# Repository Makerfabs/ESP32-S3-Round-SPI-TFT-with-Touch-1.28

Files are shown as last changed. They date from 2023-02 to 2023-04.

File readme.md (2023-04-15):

# ESP32-S3 Round SPI TFT with Touch 1.28"

```c++
/*
Version:        V1.1
Author:            Vincent
Create Date:    2023/2/18
Note:
        2023/4/15 V1.1:Add TFT_eSPI support.
*/
```

[TOC]

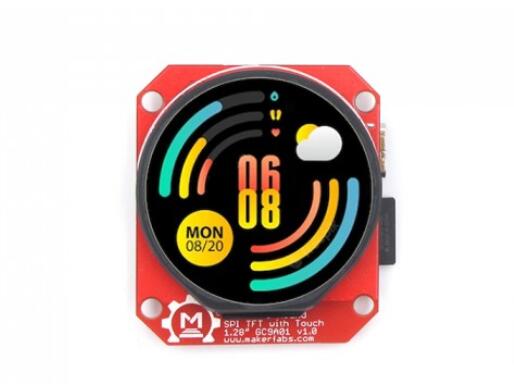
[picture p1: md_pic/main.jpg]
main


# Makerfabs

[Makerfabs home page](https://www.makerfabs.com/)

[Makerfabs Wiki](https://wiki.makerfabs.com/)

# ESP32-S3 Round SPI TFT with Touch 1.28"

## Intruduce

Product Link ：[ESP32-S3 Round SPI TFT with Touch 1.28"](https://www.makerfabs.com/esp32-s3-round-spi-tft-with-touch-1-28-inch.html)

Wiki Link : []()

The ESP32-S3 round display with touch can be a great tool for your applications such as smartwatch.

We selected the ESP32-S3 generation as the controller, with 16MB Flash and 8MB PSRAM, enough for most IOT applications; The round display is 240x240 resolution 1.28", colorful RGB, with capacitive touch, it communicates with ESP32 with SPI interface, so there enough GPIO left for expansion applications.

## Feature

- Controller: ESP32-S3
- Wireless: WiFi& Bluetooth 5.0
- LCD: 1.28", 240*240 resolution, driver GC9A01
- LCD interface: SPI
- Touch Panel Driver: CST816S
- USB: USB Native
- Power Supply: USB Type-C 5.0V(4.0V~5.25V); 3.7V Lipo battery
- Button: Flash button and reset button
- Mabee interface: 1*I2C; 1*GPIO
- MicroSD: Yes
- Arduino support: Yes
- Operation temperature: -40℃ to +85℃

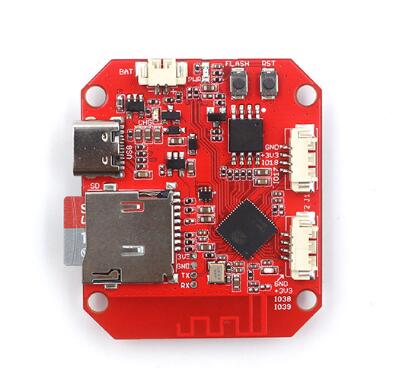
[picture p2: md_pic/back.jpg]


# Code

## Complier Option

- Install board : ESP32 .
- Install libraries：

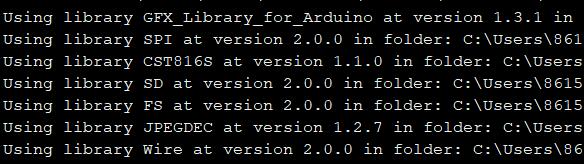
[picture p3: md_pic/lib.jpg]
library


- Use type-c use cable connect USB to PC.
- Select "ESP32-S3 DEV Module"

"mf_Lvgl" library is modified from Lvgl library (version 8.3.2). 

If you want use lvgl, please unzip "lib/mf_Lvgl.zip" and copy to arduino library directory.

## Factory test program

\example\esp32s3_round_test

You can run this file test if you feel that your hardware is not working properly. 

Need copy logo_240240.jpg to sd card.

## Example

### TFT_eSPI demo

Add TFT_eSPI support.

Library version is 2.5.0

And cover "User_Setuo.h" to library directry.

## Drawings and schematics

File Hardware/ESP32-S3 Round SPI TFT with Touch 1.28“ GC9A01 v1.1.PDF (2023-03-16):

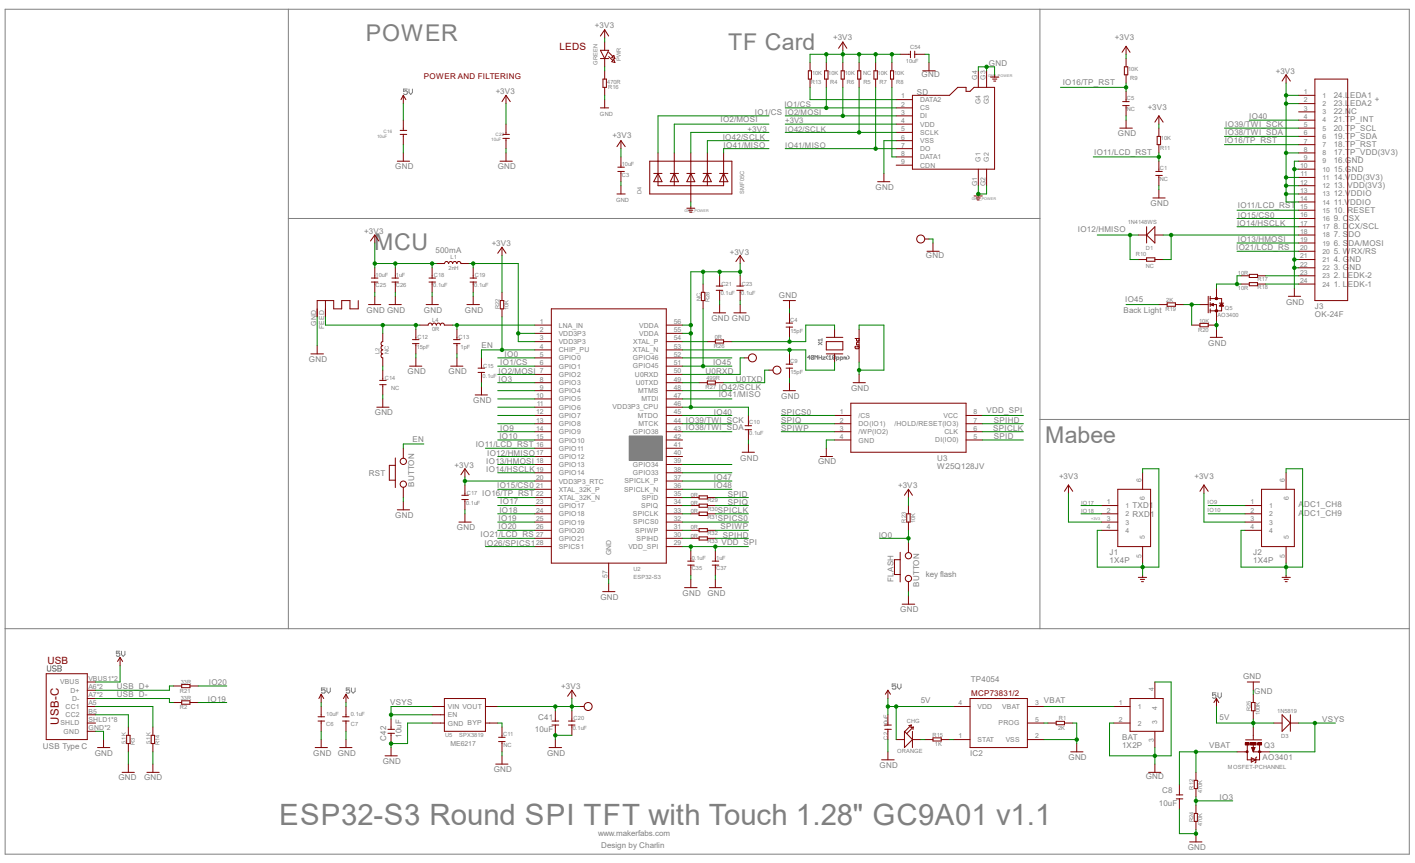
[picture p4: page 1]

IO13/HMOSI R20 | 19 19

key flash ESP32-S3 Round SPI TFT with Touch 1.28" GC9A01 v1.1

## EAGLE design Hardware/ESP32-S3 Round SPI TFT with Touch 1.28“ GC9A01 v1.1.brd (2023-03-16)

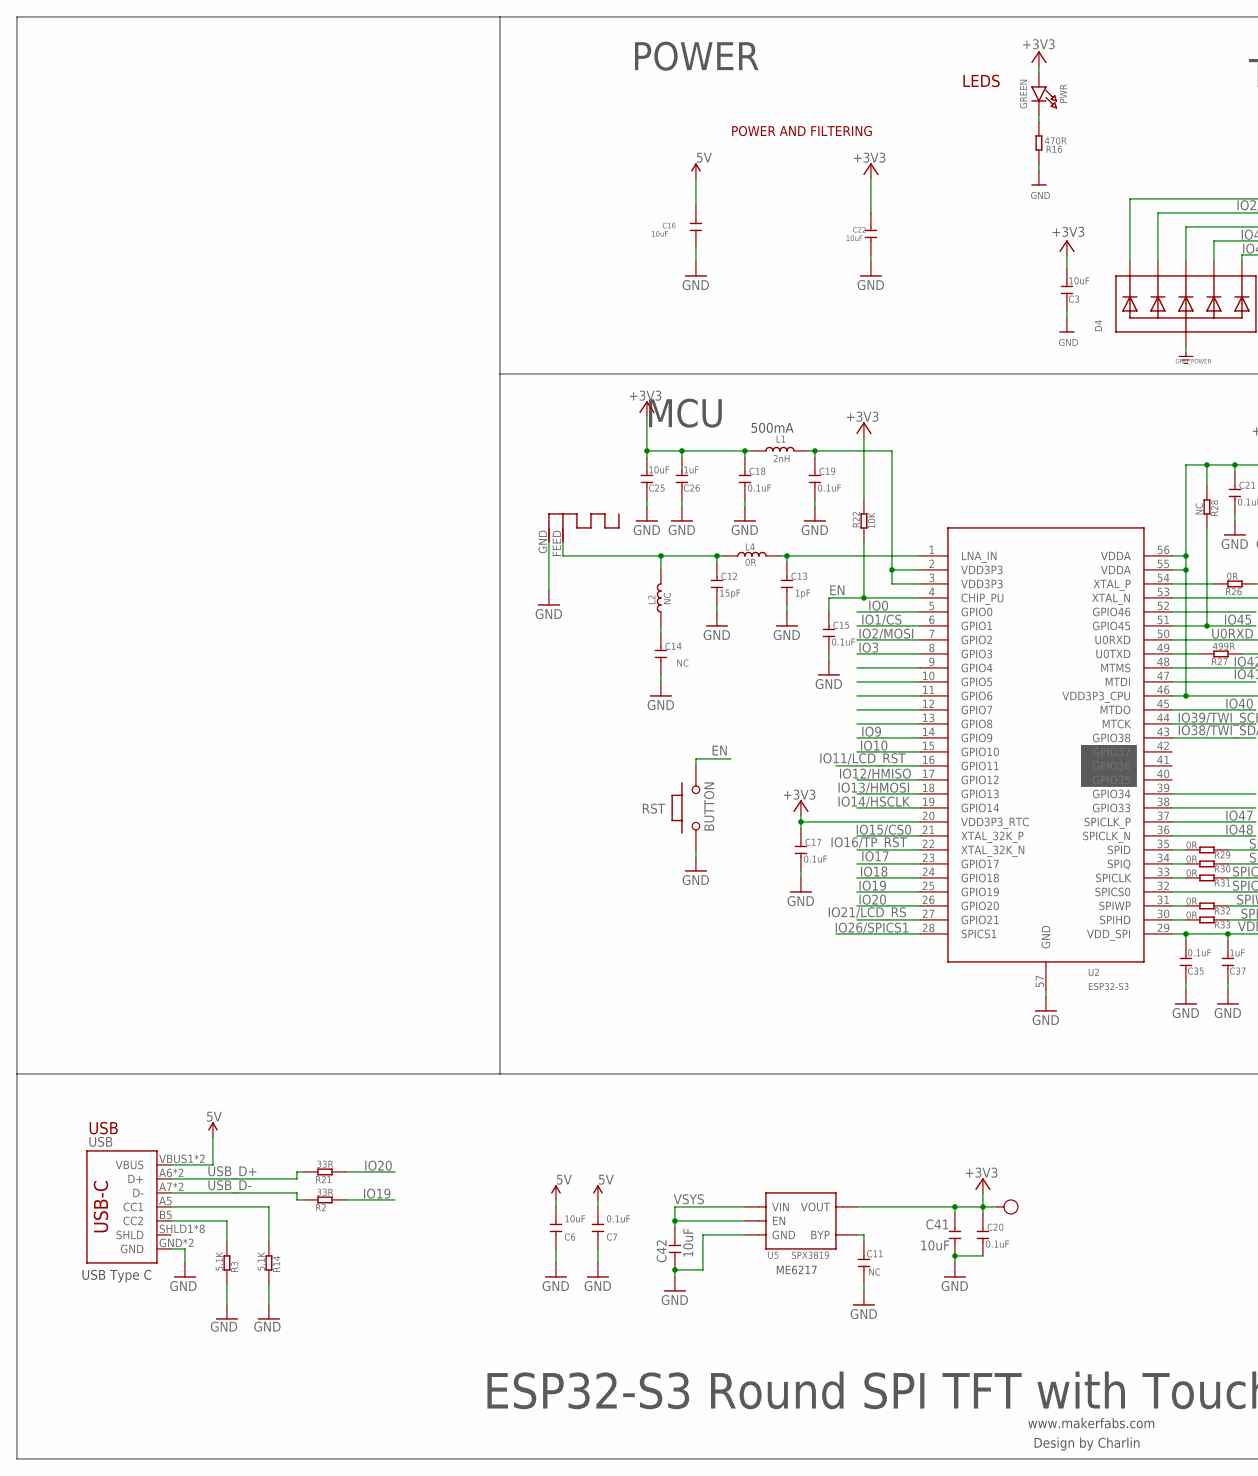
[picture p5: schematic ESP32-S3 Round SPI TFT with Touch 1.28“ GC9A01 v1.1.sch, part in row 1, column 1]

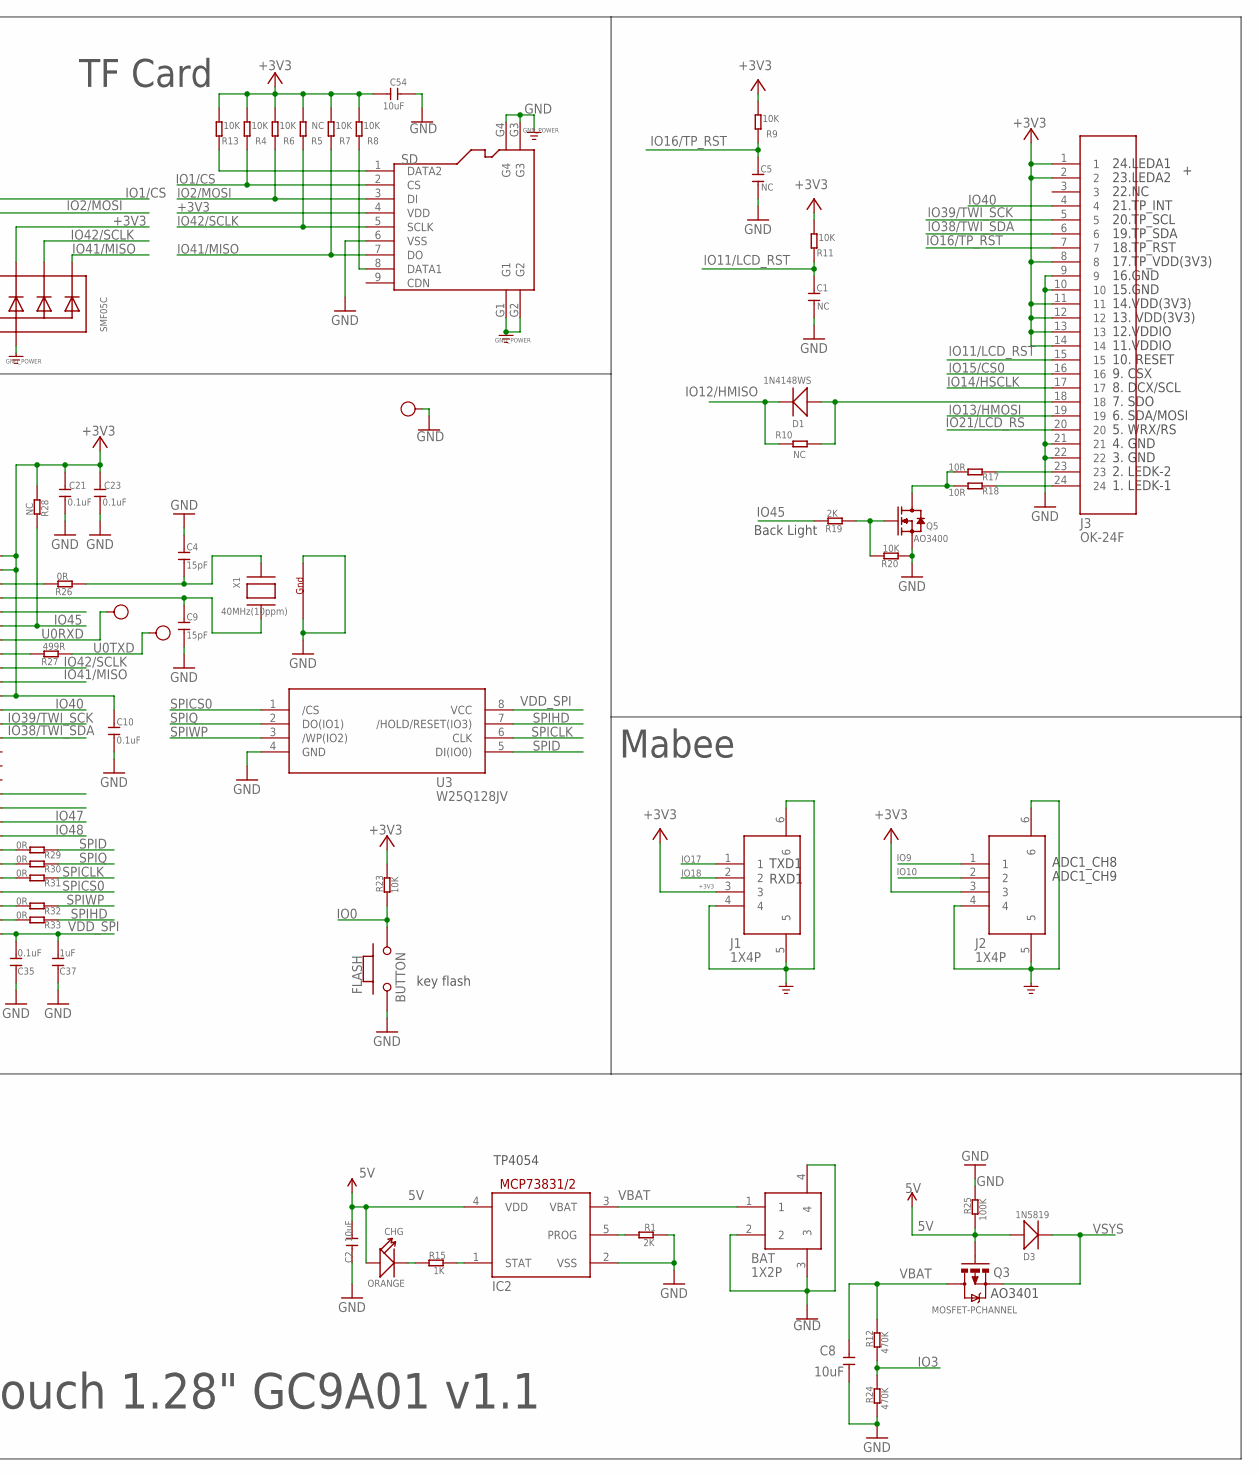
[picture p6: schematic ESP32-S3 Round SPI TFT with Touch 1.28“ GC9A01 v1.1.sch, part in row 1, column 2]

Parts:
3V3: TEST-POINT'4545'; TP-D45MIL; PARTNO DNP
ANT1: ANTENNA; RN-ANT
BAT: 1X2P; 1X2P-SMT1.25MM
C1, C5, C11, C14: NC; DISCRETE_C0402
C2, C8, C16, C22, C41, C42: 10uF; C0603
C3, C6, C25, C54: 10uF; DISCRETE_C0603
C4, C9, C12: 15pF; DISCRETE_C0402
C7, C35: 0.1uF; DISCRETE_C0603
C10, C15, C17, C18, C19, C20, C21, C23: 0.1uF; DISCRETE_C0402
C13: 1pF; DISCRETE_C0402
C26, C37: 1uF; DISCRETE_C0603
CHG: ORANGE; D0603
D1: 1N4148WS; SOD323
D3: 1N5819; SOD323
D4: SMF05C; SOT363
FLASH: BUTTON; 157SW
GND: TEST-POINT'4545'; TP-D45MIL
IC2: MCP73831/OT; SOT23-5L
J1, J2: 1X4P; 1X4P-SMT1.25MM
J3: OK-24F; OK-24F-0.4
L1: 2nH; DISCRETE_L0603
L2: NC; DISCRETE_L0402
L4: 0R; DISCRETE_L0402
PWR: GREEN; CHIPLED_0805_NOOUTLINE
Q3: MOSFET-PCHANNEL; SOT23-3
Q5: AO3400; SOT23@1
R1, R19: 2K; DISCRETE_R0402
R2, R21: 33R; DISCRETE_R0402
R3, R14: 5.1K; DISCRETE_R0402
R4, R6, R7, R8, R9, R11, R13, R20, R22, R23: 10K; DISCRETE_R0402
R5, R28: NC; DISCRETE_R0402
R10: NC; R0603
R12, R24: 470K; DISCRETE_R0402
R15: 1K; DISCRETE_R0402
R16: 470R; DISCRETE_R0402
R17, R18: 10R; DISCRETE_R0402
R25: 100K; DISCRETE_R0402
R26, R29, R30, R31, R32, R33: 0R; DISCRETE_R0402
R27: 499R; DISCRETE_R0402
RST: BUTTON; 157SW
RX: TEST-POINT'4545'; TP-D45MIL; PARTNO DNP
SD: HOLDER-MICROSD-9P; 9P-SMD-W/-RING
TX: TEST-POINT'4545'; TP-D45MIL; PARTNO DNP
U2: ESP32-S3; QFN56-7*7MM
U3: W25Q128JV; SOIC-8-208MIL
U5: SPX3819; SOT23-5
USB: USB_C5; USB-C-16P-5
X1: 40MHz(10ppm); NX3225

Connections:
5V: C2.2, C6.2, C7.2, C16.1, CHG.+, D3.+, IC2.4 (VDD), Q3.1 (G), R25.1, USB.VBUS1 (VBUS), USB.VBUS2 (VBUS)
+3V3: 3V3.T, C3.2, C10.2, C17.2, C18.2, C20.2, C21.2, C22.1, C23.2, C25.2, C26.2, C41.2, C54.2, D4.4 (C3), J1.3, J2.3, J3.1, J3.2, J3.8, J3.11, J3.12, J3.13, J3.14, L1.1, PWR.A, R4.2, R5.2, R6.2, R7.2, R8.2, R9.2, R11.2, R13.2, R22.2, R23.2, R28.1, SD.4 (VDD), U2.20 (VDD3P3_RTC), U2.46 (VDD3P3_CPU), U2.55 (VDDA), U2.56 (VDDA), U5.5 (VOUT)
EN: C15.2, R22.1, RST.2, U2.4 (CHIP_PU)
GND: ANT1.GND, BAT.2, BAT.3, BAT.4, C1.1, C2.1, C3.1, C4.2, C5.1, C6.1, C7.1, C8.1, C9.1, C10.1, C11.1, C12.1, C13.1, C14.1, C15.1, C16.2, C17.1, C18.1, C19.1, C20.1, C21.1, C22.2, C23.1, C25.1, C26.1, C35.1, C37.1, C41.1, C42.1, C54.1, D4.2 (A), FLASH.1, GND.T, IC2.2 (VSS), J1.4, J1.5, J1.6, J2.4, J2.5, J2.6, J3.9, J3.10, J3.21, J3.22, Q5.2 (S), R1.2, R3.2, R14.2, R16.1, R20.1, R24.1, R25.2, RST.1, SD.6 (VSS), SD.G1, SD.G2, SD.G3, SD.G4, U2.57 (GND), U3.4 (GND), U5.2 (GND), USB.GND, USB.GND2 (GND), X1.2 (G2), X1.4 (G1)
IO0: FLASH.2, R23.1, U2.5 (GPIO0)
IO1/CS: D4.1 (C1), R4.1, SD.2 (CS), U2.6 (GPIO1)
IO2/MOSI: D4.3 (C2), R6.1, SD.3 (DI), U2.7 (GPIO2)
IO3: R12.1, R24.2, U2.8 (GPIO3)
IO9: J2.1, U2.14 (GPIO9)
IO10: J2.2, U2.15 (GPIO10)
IO11/LCD_RST: C1.2, J3.15, R11.1, U2.16 (GPIO11)
IO12/HMISO: D1.-, R10.1, U2.17 (GPIO12)
IO13/HMOSI: J3.19, U2.18 (GPIO13)
IO14/HSCLK: J3.17, U2.19 (GPIO14)
IO15/CS0: J3.16, U2.21 (XTAL_32K_P)
IO16/TP_RST: C5.2, J3.7, R9.1, U2.22 (XTAL_32K_N)
IO17: J1.1, U2.23 (GPIO17)
IO18: J1.2, U2.24 (GPIO18)
IO19: R2.1, U2.25 (GPIO19)
IO20: R21.1, U2.26 (GPIO20)
IO21/LCD_RS: J3.20, U2.27 (GPIO21)
IO26/SPICS1: U2.28 (SPICS1)
IO38/TWI_SDA: J3.6, U2.43 (GPIO38)
IO39/TWI_SCK: J3.5, U2.44 (MTCK)
IO40: J3.4, U2.45 (MTDO)
IO41/MISO: D4.6 (C5), R7.1, SD.7 (DO), U2.47 (MTDI)
IO42/SCLK: D4.5 (C4), R5.1, SD.5 (SCLK), U2.48 (MTMS)
IO45: R19.2, R28.2, U2.51 (GPIO45)
IO47: U2.37 (SPICLK_P)
IO48: U2.36 (SPICLK_N)
unnamed: D1.+, J3.18, R10.2
unnamed: IC2.5 (PROG), R1.1
unnamed: R14.1, USB.A5 (CC1)
unnamed: PWR.C, R16.2
unnamed: R3.1, USB.B5 (CC2)
unnamed: Q5.1 (G), R19.1, R20.2
unnamed: J3.23, R17.1
unnamed: Q5.3 (D), R17.2, R18.2
unnamed: CHG.-, R15.1
unnamed: IC2.1 (STAT), R15.2
unnamed: ANT1.FEED, C12.2, L2.2, L4.1
unnamed: C13.2, L4.2, U2.1 (LNA_IN)
unnamed: R29.2, U2.35 (SPID)
unnamed: C19.2, L1.2, U2.2 (VDD3P3), U2.3 (VDD3P3)
unnamed: C14.2, L2.1
unnamed: R30.2, U2.34 (SPIQ)
unnamed: R26.2, U2.54 (XTAL_P)
unnamed: R31.2, U2.33 (SPICLK)
unnamed: R32.2, U2.31 (SPIWP)
unnamed: R33.2, U2.30 (SPIHD)
unnamed: R13.1, SD.1 (DATA2)
unnamed: R8.1, SD.8 (DATA1)
unnamed: R27.2, U2.49 (U0TXD)
unnamed: C9.2, U2.53 (XTAL_N), X1.3 (X2)
unnamed: C4.1, R26.1, X1.1 (X1)
unnamed: J3.24, R18.1
unnamed: C11.2, U5.4 (BYP)
SPICLK: R31.1, U3.6 (CLK)
SPICS0: U2.32 (SPICS0), U3.1 (/CS)
SPID: R29.1, U3.5 (DI(IO0))
SPIHD: R33.1, U3.7 (/HOLD/RESET(IO3))
SPIQ: R30.1, U3.2 (DO(IO1))
SPIWP: R32.1, U3.3 (/WP(IO2))
U0RXD: RX.T, U2.50 (U0RXD)
U0TXD: R27.1, TX.T
USB_D+: R21.2, USB.A6 (D+), USB.B6 (D+)
USB_D-: R2.2, USB.A7 (D-), USB.B7 (D-)
VBAT: BAT.1, C8.2, IC2.3 (VBAT), Q3.3 (D), R12.2
VDD_SPI: C35.2, C37.2, U2.29 (VDD_SPI), U3.8 (VCC)
VSYS: C42.2, D3.-, Q3.2 (S), U5.1 (VIN), U5.3 (EN)

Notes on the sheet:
www.makerfabs.com
Design by Charlin
LEDS
POWER AND FILTERING
key flash
ESP32-S3 Round SPI TFT with Touch 1.28" GC9A01 v1.1
POWER
TF Card
USB
USB Type C
Mabee
MCU
500mA
ME6217
1. LEDK-1
2. LEDK-2
3. GND
4. GND
5. WRX/RS
6. SDA/MOSI
7. SDO
8. DCX/SCL
9. CSX
10. RESET
11.VDDIO
12.VDDIO
13. VDD(3V3)
14.VDD(3V3)
15.GND
16.GND
17.TP_VDD(3V3)
18.TP_RST
19.TP_SDA
20.TP_SCL
21.TP_INT
22.NC
23.LEDA2
24.LEDA1
Back Light
ADC1_CH8

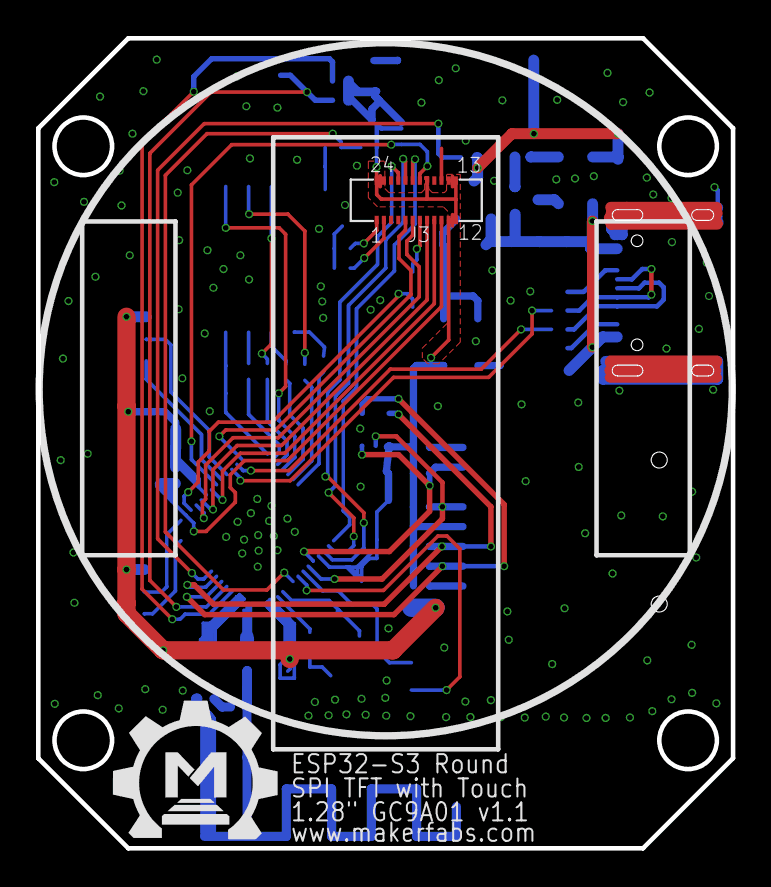
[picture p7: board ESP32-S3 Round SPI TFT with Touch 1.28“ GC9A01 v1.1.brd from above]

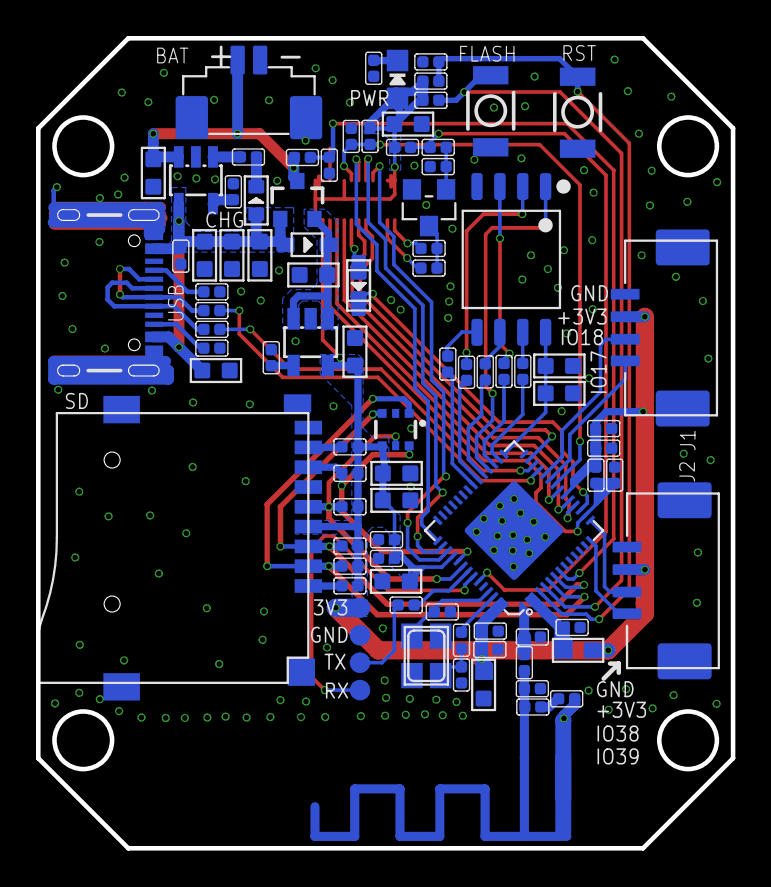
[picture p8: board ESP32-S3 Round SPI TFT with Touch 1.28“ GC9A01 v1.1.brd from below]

Board: 2 copper layers, 38.6 x 45.0 mm, 92 parts (90 on the bottom side), 67 nets.

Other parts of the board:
U$1: MAKERFABS_0.3

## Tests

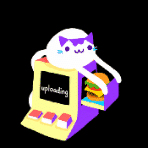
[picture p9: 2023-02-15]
example/s3_round_gif/gif/test3.gif

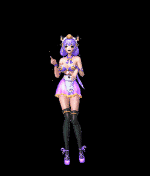
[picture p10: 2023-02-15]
example/s3_round_gif/gif/test4.gif

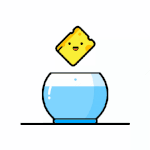
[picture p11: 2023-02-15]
example/s3_round_gif/gif/test1.gif

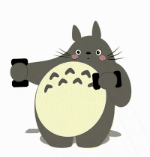
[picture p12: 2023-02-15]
example/s3_round_gif/gif/test2.gif

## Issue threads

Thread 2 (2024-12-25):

error: 'USBSerial' was not declared in this scope; did you mean 'Serial'?

r03ert0, 2024-12-25:
Hello,

When I try to upload esp32s3_round_test.ino to a matouch 1.28, I get the following error:

```
ESP32-S3-Round-SPI-TFT-with-Touch-1.28-main/example/esp32s3_round_test/esp32s3_round_test.ino: In function 'void setup()':
esp32s3_round_test:34:5: error: 'USBSerial' was not declared in this scope; did you mean 'Serial'?
   34 |     USBSerial.begin(115200);
      |     ^~~~~~~~~
      |     Serial
Multiple libraries were found for "SD.h"
 Used: /Users/roberto/Library/Arduino15/packages/esp32/hardware/esp32/3.1.0/libraries/SD
 Not used: /Users/roberto/Documents/Arduino/libraries/SD
exit status 1
'USBSerial' was not declared in this scope; did you mean 'Serial'?
```

what can be wrong?

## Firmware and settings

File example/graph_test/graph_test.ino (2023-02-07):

#include <Arduino_GFX_Library.h>

#define TFT_BLK 45
#define TFT_RES 11

#define TFT_CS 15
#define TFT_MOSI 13
#define TFT_MISO 12
#define TFT_SCLK 14
#define TFT_DC 21

Arduino_ESP32SPI *bus = new Arduino_ESP32SPI(TFT_DC, TFT_CS, TFT_SCLK, TFT_MOSI, TFT_MISO, HSPI, true); // Constructor

Arduino_GFX *gfx = new Arduino_GC9A01(bus, TFT_RES, 0 /* rotation */, true /* IPS */);

int32_t w, h, n, n1, cx, cy, cx1, cy1, cn, cn1;
uint8_t tsa, tsb, tsc, ds;

void setup()
{
    USBSerial.begin(115200);

    pinMode(TFT_BLK, OUTPUT);
    digitalWrite(TFT_BLK, 1);

    delay(1000);
    USBSerial.println("start");

    gfx->begin();
    // gfx->begin(80000000); /* specify data bus speed */

    w = gfx->width();
    h = gfx->height();
    n = min(w, h);
    n1 = n - 1;
    cx = w / 2;
    cy = h / 2;
    cx1 = cx - 1;
    cy1 = cy - 1;
    cn = min(cx1, cy1);
    cn1 = cn - 1;
    tsa = ((w <= 176) || (h <= 160)) ? 1 : (((w <= 240) || (h <= 240)) ? 2 : 3); // text size A
    tsb = ((w <= 272) || (h <= 220)) ? 1 : 2;                                    // text size B
    tsc = ((w <= 220) || (h <= 220)) ? 1 : 2;                                    // text size C
    ds = (w <= 160) ? 9 : 12;                                                    // digit size

#ifdef GFX_BL
    pinMode(GFX_BL, OUTPUT);
    digitalWrite(GFX_BL, HIGH);
#endif
}

static inline uint32_t micros_start() __attribute__((always_inline));
static inline uint32_t micros_start()
{
    uint8_t oms = millis();
    while ((uint8_t)millis() == oms)
        ;
    return micros();
}

void loop(void)
{
    USBSerial.println(F("Benchmark\tmicro-secs"));

    int32_t usecFillScreen = testFillScreen();
    serialOut(F("Screen fill\t"), usecFillScreen, 100, true);

    int32_t usecText = testText();
    serialOut(F("Text\t"), usecText, 3000, true);

    int32_t usecPixels = testPixels();
    serialOut(F("Pixels\t"), usecPixels, 100, true);

    int32_t usecLines = testLines();
    serialOut(F("Lines\t"), usecLines, 100, true);

    int32_t usecFastLines = testFastLines();
    serialOut(F("Horiz/Vert Lines\t"), usecFastLines, 100, true);

    int32_t usecFilledRects = testFilledRects();
    serialOut(F("Rectangles (filled)\t"), usecFilledRects, 100, false);

    int32_t usecRects = testRects();
    serialOut(F("Rectangles (outline)\t"), usecRects, 100, true);

    int32_t usecFilledTrangles = testFilledTriangles();
    serialOut(F("Triangles (filled)\t"), usecFilledTrangles, 100, false);

    int32_t usecTriangles = testTriangles();
    serialOut(F("Triangles (outline)\t"), usecTriangles, 100, true);

    int32_t usecFilledCircles = testFilledCircles(10);
    serialOut(F("Circles (filled)\t"), usecFilledCircles, 100, false);

    int32_t usecCircles = testCircles(10);
    serialOut(F("Circles (outline)\t"), usecCircles, 100, true);

    int32_t usecFilledArcs = testFillArcs();
    serialOut(F("Arcs (filled)\t"), usecFilledArcs, 100, false);

    int32_t usecArcs = testArcs();
    serialOut(F("Arcs (outline)\t"), usecArcs, 100, true);

    int32_t usecFilledRoundRects = testFilledRoundRects();
    serialOut(F("Rounded rects (filled)\t"), usecFilledRoundRects, 100, false);

    int32_t usecRoundRects = testRoundRects();
    serialOut(F("Rounded rects (outline)\t"), usecRoundRects, 100, true);

#ifdef CANVAS
    uint32_t start = micros_start();
    gfx->flush();
    int32_t usecFlush = micros() - start;
    serialOut(F("flush (Canvas only)\t"), usecFlush, 0, false);
#endif

    USBSerial.println(F("Done!"));

    uint16_t c = 4;
    int8_t d = 1;
    for (int32_t i = 0; i < h; i++)
    {
        gfx->drawFastHLine(0, i, w, c);
        c += d;
        if (c <= 4 || c >= 11)
        {
            d = -d;
        }
    }

    gfx->setCursor(0, 0);

    gfx->setTextSize(tsa);
    gfx->setTextColor(MAGENTA);
    gfx->println(F("Arduino GFX PDQ"));

    if (h > w)
    {
        gfx->setTextSize(tsb);
        gfx->setTextColor(GREEN);
        gfx->print(F("\nBenchmark "));
        gfx->setTextSize(tsc);
        if (ds == 12)
        {
            gfx->print(F("   "));
        }
        gfx->println(F("micro-secs"));
    }

    printnice(F("Screen fill "), usecFillScreen);
    printnice(F("Text        "), usecText);
    printnice(F("Pixels      "), usecPixels);
    printnice(F("Lines       "), usecLines);
    printnice(F("H/V Lines   "), usecFastLines);
    printnice(F("Rectangles F"), usecFilledRects);
    printnice(F("Rectangles  "), usecRects);
    printnice(F("Triangles F "), usecFilledTrangles);
    printnice(F("Triangles   "), usecTriangles);
    printnice(F("Circles F   "), usecFilledCircles);
    printnice(F("Circles     "), usecCircles);
    printnice(F("Arcs F      "), usecFilledArcs);
    printnice(F("Arcs        "), usecArcs);
    printnice(F("RoundRects F"), usecFilledRoundRects);
    printnice(F("RoundRects  "), usecRoundRects);

    if ((h > w) || (h > 240))
    {
        gfx->setTextSize(tsc);
        gfx->setTextColor(GREEN);
        gfx->print(F("\nBenchmark Complete!"));
    }

#ifdef CANVAS
    gfx->flush();
#endif

    delay(60 * 1000L);
}

void serialOut(const __FlashStringHelper *item, int32_t v, uint32_t d, bool clear)
{
#ifdef CANVAS
    gfx->flush();
#endif
    USBSerial.print(item);
    if (v < 0)
    {
        USBSerial.println(F("N/A"));
    }
    else
    {
        USBSerial.println(v);
    }
    delay(d);
    if (clear)
    {
        gfx->fillScreen(BLACK);
    }
}

void printnice(const __FlashStringHelper *item, long int v)
{
    gfx->setTextSize(tsb);
    gfx->setTextColor(CYAN);
    gfx->print(item);

    gfx->setTextSize(tsc);
    gfx->setTextColor(YELLOW);
    if (v < 0)
    {
        gfx->println(F("      N / A"));
    }
    else
    {
        char str[32] = {0};
#ifdef RTL8722DM
        sprintf(str, "%d", (int)v);
#else
        sprintf(str, "%ld", v);
#endif
        for (char *p = (str + strlen(str)) - 3; p > str; p -= 3)
        {
            memmove(p + 1, p, strlen(p) + 1);
            *p = ',';
        }
        while (strlen(str) < ds)
        {
            memmove(str + 1, str, strlen(str) + 1);
            *str = ' ';
        }
        gfx->println(str);
    }
}

int32_t testFillScreen()
{
    uint32_t start = micros_start();
    // Shortened this tedious test!
    gfx->fillScreen(WHITE);
    gfx->fillScreen(RED);
    gfx->fillScreen(GREEN);
    gfx->fillScreen(BLUE);
    gfx->fillScreen(BLACK);

    return micros() - start;
}

int32_t testText()
{
    uint32_t start = micros_start();
    gfx->setCursor(0, 0);

    gfx->setTextSize(1);
    gfx->setTextColor(WHITE, BLACK);
    gfx->println(F("Hello World!"));

    gfx->setTextSize(2);
    gfx->setTextColor(gfx->color565(0xff, 0x00, 0x00));
    gfx->print(F("RED "));
    gfx->setTextColor(gfx->color565(0x00, 0xff, 0x00));
    gfx->print(F("GREEN "));
    gfx->setTextColor(gfx->color565(0x00, 0x00, 0xff));
    gfx->println(F("BLUE"));

    gfx->setTextSize(tsa);
    gfx->setTextColor(YELLOW);
    gfx->println(1234.56);

    gfx->setTextColor(WHITE);
    gfx->println((w > 128) ? 0xDEADBEEF : 0xDEADBEE, HEX);

    gfx->setTextColor(CYAN, WHITE);
    gfx->println(F("Groop,"));

    gfx->setTextSize(tsc);
    gfx->setTextColor(MAGENTA, WHITE);
    gfx->println(F("I implore thee,"));

    gfx->setTextSize(1);
    gfx->setTextColor(NAVY, WHITE);
    gfx->println(F("my foonting turlingdromes."));

    gfx->setTextColor(DARKGREEN, WHITE);
    gfx->println(F("And hooptiously drangle me"));

    gfx->setTextColor(DARKCYAN, WHITE);
    gfx->println(F("with crinkly bindlewurdles,"));

    gfx->setTextColor(MAROON, WHITE);
    gfx->println(F("Or I will rend thee"));

    gfx->setTextColor(PURPLE, WHITE);
    gfx->println(F("in the gobberwartsb"));

    gfx->setTextColor(OLIVE, WHITE);
    gfx->println(F("with my blurglecruncheon,"));

    gfx->setTextColor(DARKGREY, WHITE);
    gfx->println(F("see if I don't!"));

    gfx->setTextSize(2);
    gfx->setTextColor(RED);
    gfx->println(F("Size 2"));

    gfx->setTextSize(3);
    gfx->setTextColor(ORANGE);
    gfx->println(F("Size 3"));

    gfx->setTextSize(4);
    gfx->setTextColor(YELLOW);
    gfx->println(F("Size 4"));

    gfx->setTextSize(5);
    gfx->setTextColor(GREENYELLOW);
    gfx->println(F("Size 5"));

    gfx->setTextSize(6);
    gfx->setTextColor(GREEN);
    gfx->println(F("Size 6"));

    gfx->setTextSize(7);
    gfx->setTextColor(BLUE);
    gfx->println(F("Size 7"));

    gfx->setTextSize(8);
    gfx->setTextColor(PURPLE);
    gfx->println(F("Size 8"));

    gfx->setTextSize(9);
    gfx->setTextColor(PINK);
    gfx->println(F("Size 9"));

    return micros() - start;
}

int32_t testPixels()
{
    uint32_t start = micros_start();

    for (int16_t y = 0; y < h; y++)
    {
        for (int16_t x = 0; x < w; x++)
        {
            gfx->drawPixel(x, y, gfx->color565(x << 3, y << 3, x * y));
        }
#ifdef ESP8266
        yield(); // avoid long run triggered ESP8266 WDT restart
#endif
    }

    return micros() - start;
}

int32_t testLines()
{
    uint32_t start;
    int32_t x1, y1, x2, y2;

    start = micros_start();

    x1 = y1 = 0;
    y2 = h - 1;
    for (x2 = 0; x2 < w; x2 += 6)
    {
        gfx->drawLine(x1, y1, x2, y2, BLUE);
    }
#ifdef ESP8266
    yield(); // avoid long run triggered ESP8266 WDT restart
#endif

    x2 = w - 1;
    for (y2 = 0; y2 < h; y2 += 6)
    {
        gfx->drawLine(x1, y1, x2, y2, BLUE);
    }
#ifdef ESP8266
    yield(); // avoid long run triggered ESP8266 WDT restart
#endif

    x1 = w - 1;
    y1 = 0;
    y2 = h - 1;
    for (x2 = 0; x2 < w; x2 += 6)
    {
        gfx->drawLine(x1, y1, x2, y2, BLUE);
    }
#ifdef ESP8266
    yield(); // avoid long run triggered ESP8266 WDT restart
#endif

    x2 = 0;
    for (y2 = 0; y2 < h; y2 += 6)
    {
        gfx->drawLine(x1, y1, x2, y2, BLUE);
    }
#ifdef ESP8266
    yield(); // avoid long run triggered ESP8266 WDT restart
#endif

    x1 = 0;
    y1 = h - 1;
    y2 = 0;
    for (x2 = 0; x2 < w; x2 += 6)
    {
        gfx->drawLine(x1, y1, x2, y2, BLUE);
    }
#ifdef ESP8266
    yield(); // avoid long run triggered ESP8266 WDT restart
#endif

    x2 = w - 1;
    for (y2 = 0; y2 < h; y2 += 6)
    {
        gfx->drawLine(x1, y1, x2, y2, BLUE);
    }
#ifdef ESP8266
    yield(); // avoid long run triggered ESP8266 WDT restart
#endif

    x1 = w - 1;
    y1 = h - 1;
    y2 = 0;
    for (x2 = 0; x2 < w; x2 += 6)
    {
        gfx->drawLine(x1, y1, x2, y2, BLUE);
    }
#ifdef ESP8266
    yield(); // avoid long run triggered ESP8266 WDT restart
#endif

    x2 = 0;
    for (y2 = 0; y2 < h; y2 += 6)
    {
        gfx->drawLine(x1, y1, x2, y2, BLUE);
    }
#ifdef ESP8266
    yield(); // avoid long run triggered ESP8266 WDT restart
#endif

    return micros() - start;
}

int32_t testFastLines()
{
    uint32_t start;
    int32_t x, y;

    start = micros_start();

    for (y = 0; y < h; y += 5)
    {
        gfx->drawFastHLine(0, y, w, RED);
    }
    for (x = 0; x < w; x += 5)
    {
        gfx->drawFastVLine(x, 0, h, BLUE);
    }

    return micros() - start;
}

int32_t testFilledRects()
{
    uint32_t start;
    int32_t i, i2;

    start = micros_start();

    for (i = n; i > 0; i -= 6)
    {
        i2 = i / 2;

        gfx->fillRect(cx - i2, cy - i2, i, i, gfx->color565(i, i, 0));
    }

    return micros() - start;
}

int32_t testRects()
{
    uint32_t start;
    int32_t i, i2;

    start = micros_start();
    for (i = 2; i < n; i += 6)
    {
        i2 = i / 2;
        gfx->drawRect(cx - i2, cy - i2, i, i, GREEN);
    }

    return micros() - start;
}

int32_t testFilledCircles(uint8_t radius)
{
    uint32_t start;
    int32_t x, y, r2 = radius * 2;

    start = micros_start();

    for (x = radius; x < w; x += r2)
    {
        for (y = radius; y < h; y += r2)
        {
            gfx->fillCircle(x, y, radius, MAGENTA);
        }
    }

    return micros() - start;
}

int32_t testCircles(uint8_t radius)
{
    uint32_t start;
    int32_t x, y, r2 = radius * 2;
    int32_t w1 = w + radius;
    int32_t h1 = h + radius;

    // Screen is not cleared for this one -- this is
    // intentional and does not affect the reported time.
    start = micros_start();

    for (x = 0; x < w1; x += r2)
    {
        for (y = 0; y < h1; y += r2)
        {
            gfx->drawCircle(x, y, radius, WHITE);
        }
    }

    return micros() - start;
}

int32_t testFillArcs()
{
    int16_t i, r = 360 / cn;
    uint32_t start = micros_start();

    for (i = 6; i < cn; i += 6)
    {
        gfx->fillArc(cx1, cy1, i, i - 3, 0, i * r, RED);
    }

    return micros() - start;
}

int32_t testArcs()
{
    int16_t i, r = 360 / cn;
    uint32_t start = micros_start();

    for (i = 6; i < cn; i += 6)
    {
        gfx->drawArc(cx1, cy1, i, i - 3, 0, i * r, WHITE);
    }

    return micros() - start;
}

int32_t testFilledTriangles()
{
    uint32_t start;
    int32_t i;

    start = micros_start();

    for (i = cn1; i > 10; i -= 5)
    {
        gfx->fillTriangle(cx1, cy1 - i, cx1 - i, cy1 + i, cx1 + i, cy1 + i,
                          gfx->color565(0, i, i));
    }

    return micros() - start;
}

int32_t testTriangles()
{
    uint32_t start;
    int32_t i;

    start = micros_start();

    for (i = 0; i < cn; i += 5)
    {
        gfx->drawTriangle(
            cx1, cy1 - i,     // peak
            cx1 - i, cy1 + i, // bottom left
            cx1 + i, cy1 + i, // bottom right
            gfx->color565(0, 0, i));
    }

    return micros() - start;
}

int32_t testFilledRoundRects()
{
    uint32_t start;
    int32_t i, i2;

    start = micros_start();

    for (i = n1; i > 20; i -= 6)
    {
        i2 = i / 2;
        gfx->fillRoundRect(cx - i2, cy - i2, i, i, i / 8, gfx->color565(0, i, 0));
    }

    return micros() - start;
}

int32_t testRoundRects()
{
    uint32_t start;
    int32_t i, i2;

    start = micros_start();

    for (i = 20; i < n1; i += 6)
    {
        i2 = i / 2;
        gfx->drawRoundRect(cx - i2, cy - i2, i, i, i / 8, gfx->color565(i, 0, 0));
    }

    return micros() - start;
}

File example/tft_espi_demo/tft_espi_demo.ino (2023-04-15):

/*
 Adapted from the Adafruit graphicstest sketch, see original header at end
 of sketch.

 This sketch uses the GLCD font (font 1) only.

 Make sure all the display driver and pin connections are correct by
 editing the User_Setup.h file in the TFT_eSPI library folder.

 #########################################################################
 ###### DON'T FORGET TO UPDATE THE User_Setup.h FILE IN THE LIBRARY ######
 #########################################################################
*/

#define TFT_BLK 45
#define TFT_RES 11

#define TFT_CS 15
#define TFT_MOSI 13
#define TFT_MISO 12
#define TFT_SCLK 14
#define TFT_DC 21

#include "SPI.h"
#include "TFT_eSPI.h"

TFT_eSPI tft = TFT_eSPI();

unsigned long total = 0;
unsigned long tn = 0;
void setup()
{
    pinMode(TFT_BLK, OUTPUT);
    digitalWrite(TFT_BLK, 1);

    USBSerial.begin(115200);
    while (!USBSerial)
        ;

    USBSerial.println("");
    USBSerial.println("");
    USBSerial.println("TFT_eSPI library test!");

    tft.init();

    tn = micros();
    tft.fillScreen(TFT_BLACK);

    yield();
    USBSerial.println(F("Benchmark                Time (microseconds)"));

    yield();
    USBSerial.print(F("Screen fill              "));
    yield();
    USBSerial.println(testFillScreen());
    // total+=testFillScreen();
    // delay(500);

    yield();
    USBSerial.print(F("Text                     "));
    yield();
    USBSerial.println(testText());
    // total+=testText();
    // delay(3000);

    yield();
    USBSerial.print(F("Lines                    "));
    yield();
    USBSerial.println(testLines(TFT_CYAN));
    // total+=testLines(TFT_CYAN);
    // delay(500);

    yield();
    USBSerial.print(F("Horiz/Vert Lines         "));
    yield();
    USBSerial.println(testFastLines(TFT_RED, TFT_BLUE));
    // total+=testFastLines(TFT_RED, TFT_BLUE);
    // delay(500);

    yield();
    USBSerial.print(F("Rectangles (outline)     "));
    yield();
    USBSerial.println(testRects(TFT_GREEN));
    // total+=testRects(TFT_GREEN);
    // delay(500);

    yield();
    USBSerial.print(F("Rectangles (filled)      "));
    yield();
    USBSerial.println(testFilledRects(TFT_YELLOW, TFT_MAGENTA));
    // total+=testFilledRects(TFT_YELLOW, TFT_MAGENTA);
    // delay(500);

    yield();
    USBSerial.print(F("Circles (filled)         "));
    yield();
    USBSerial.println(testFilledCircles(10, TFT_MAGENTA));
    // total+= testFilledCircles(10, TFT_MAGENTA);

    yield();
    USBSerial.print(F("Circles (outline)        "));
    yield();
    USBSerial.println(testCircles(10, TFT_WHITE));
    // total+=testCircles(10, TFT_WHITE);
    // delay(500);

    yield();
    USBSerial.print(F("Triangles (outline)      "));
    yield();
    USBSerial.println(testTriangles());
    // total+=testTriangles();
    // delay(500);

    yield();
    USBSerial.print(F("Triangles (filled)       "));
    yield();
    USBSerial.println(testFilledTriangles());
    // total += testFilledTriangles();
    // delay(500);

    yield();
    USBSerial.print(F("Rounded rects (outline)  "));
    yield();
    USBSerial.println(testRoundRects());
    // total+=testRoundRects();
    // delay(500);

    yield();
    USBSerial.print(F("Rounded rects (filled)   "));
    yield();
    USBSerial.println(testFilledRoundRects());
    // total+=testFilledRoundRects();
    // delay(500);

    yield();
    USBSerial.println(F("Done!"));
    yield();
    // USBSerial.print(F("Total = ")); USBSerial.println(total);

    // yield();USBSerial.println(millis()-tn);
}

void loop(void)
{
    for (uint8_t rotation = 0; rotation < 4; rotation++)
    {
        tft.setRotation(rotation);
        testText();
        delay(2000);
    }
}

unsigned long testFillScreen()
{
    unsigned long start = micros();
    tft.fillScreen(TFT_BLACK);
    tft.fillScreen(TFT_RED);
    tft.fillScreen(TFT_GREEN);
    tft.fillScreen(TFT_BLUE);
    tft.fillScreen(TFT_BLACK);
    return micros() - start;
}

unsigned long testText()
{
    tft.fillScreen(TFT_BLACK);
    unsigned long start = micros();
    tft.setCursor(0, 0);
    tft.setTextColor(TFT_WHITE);
    tft.setTextSize(1);
    tft.println("Hello World!");
    tft.setTextColor(TFT_YELLOW);
    tft.setTextSize(2);
    tft.println(1234.56);
    tft.setTextColor(TFT_RED);
    tft.setTextSize(3);
    tft.println(0xDEADBEEF, HEX);
    tft.println();
    tft.setTextColor(TFT_GREEN);
    tft.setTextSize(5);
    tft.println("Groop");
    tft.setTextSize(2);
    tft.println("I implore thee,");
    // tft.setTextColor(TFT_GREEN,TFT_BLACK);
    tft.setTextSize(1);
    tft.println("my foonting turlingdromes.");
    tft.println("And hooptiously drangle me");
    tft.println("with crinkly bindlewurdles,");
    tft.println("Or I will rend thee");
    tft.println("in the gobberwarts");
    tft.println("with my blurglecruncheon,");
    tft.println("see if I don't!");
    return micros() - start;
}

unsigned long testLines(uint16_t color)
{
    unsigned long start, t;
    int x1, y1, x2, y2,
        w = tft.width(),
        h = tft.height();

    tft.fillScreen(TFT_BLACK);

    x1 = y1 = 0;
    y2 = h - 1;
    start = micros();
    for (x2 = 0; x2 < w; x2 += 6)
        tft.drawLine(x1, y1, x2, y2, color);
    x2 = w - 1;
    for (y2 = 0; y2 < h; y2 += 6)
        tft.drawLine(x1, y1, x2, y2, color);
    t = micros() - start; // fillScreen doesn't count against timing

    tft.fillScreen(TFT_BLACK);

    x1 = w - 1;
    y1 = 0;
    y2 = h - 1;
    start = micros();
    for (x2 = 0; x2 < w; x2 += 6)
        tft.drawLine(x1, y1, x2, y2, color);
    x2 = 0;
    for (y2 = 0; y2 < h; y2 += 6)
        tft.drawLine(x1, y1, x2, y2, color);
    t += micros() - start;

    tft.fillScreen(TFT_BLACK);

    x1 = 0;
    y1 = h - 1;
    y2 = 0;
    start = micros();
    for (x2 = 0; x2 < w; x2 += 6)
        tft.drawLine(x1, y1, x2, y2, color);
    x2 = w - 1;
    for (y2 = 0; y2 < h; y2 += 6)
        tft.drawLine(x1, y1, x2, y2, color);
    t += micros() - start;

    tft.fillScreen(TFT_BLACK);

    x1 = w - 1;
    y1 = h - 1;
    y2 = 0;
    start = micros();
    for (x2 = 0; x2 < w; x2 += 6)
        tft.drawLine(x1, y1, x2, y2, color);
    x2 = 0;
    for (y2 = 0; y2 < h; y2 += 6)
        tft.drawLine(x1, y1, x2, y2, color);

    return micros() - start;
}

unsigned long testFastLines(uint16_t color1, uint16_t color2)
{
    unsigned long start;
    int x, y, w = tft.width(), h = tft.height();

    tft.fillScreen(TFT_BLACK);
    start = micros();
    for (y = 0; y < h; y += 5)
        tft.drawFastHLine(0, y, w, color1);
    for (x = 0; x < w; x += 5)
        tft.drawFastVLine(x, 0, h, color2);

    return micros() - start;
}
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

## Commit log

2023-03-16 add hardware
    [ESP32-S3 Round SPI TFT with Touch 1.28“ GC9A01 v1.1.brd, ESP32-S3 Round SPI TFT with Touch 1.28“ GC9A01 v1.1.sch]
2023-10-28 Add LVGL ADC example

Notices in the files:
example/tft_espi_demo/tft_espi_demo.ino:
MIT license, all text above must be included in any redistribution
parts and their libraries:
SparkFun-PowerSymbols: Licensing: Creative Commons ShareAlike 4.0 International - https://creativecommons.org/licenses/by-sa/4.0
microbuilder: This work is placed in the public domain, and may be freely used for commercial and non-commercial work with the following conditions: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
